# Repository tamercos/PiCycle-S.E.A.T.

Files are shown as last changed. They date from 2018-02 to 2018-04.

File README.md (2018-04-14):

# PiCycle S.E.A.T.
The PiCycle S.E.A.T. (Situational and Environmental Awareness Technology) aims to combine ultrasonic sensors with a Raspberry Pi utilising haptic feedback with the objective of increasing road safety for cyclists.

HC-SR04 ultrasonic sensors placed under the seat of the bicycle facing backwards will detect the approach of foreign objects and alert the cyclist via small vibration motors situated within the rider's helmet.



The system will increase road safety for bicycle users by allowing them to 'feel' what they cannot see behind them. Current solutions rely on wearable mirrors as wrist bands. These force cyclists to take their eyes off the road infront creating more potential dangers. The PiCycle S.E.A.T enables continuous blind spot observation without distracting the cyclist.

**A short video demonstrating the device prototype can be found here:**

https://www.youtube.com/watch?v=8pkJoHdxL40&feature=youtu.be

## Parts Used
The list below highlights some of the key hardware needed to replicate this project. Please note that circuit components can be found in the circuit schematic. A full list of this hardware with cost at time of completion is also given in "Project Components and Expenditure.xlsx"

- 3x HC-SR04 ultrasonic sensors
- 3x Seed mini vibration motor 3V 2.0mm circular
- 3D printed parts found under the "PiCycleSEAT 3D Print" folder
- 5x M2.5 x 8mm screws for the housing lid
- 4x M2.5 x 6mm screws for Raspberry Pi
- 1x Makibes Touch Screen 3.5" Resistive LCD
- 1x Long pin stack header
- 1x Perma-proto hat for Raspberry Pi Adafruit Perma-Proto Pi HAT!
- 1x 26 connection ribbon cable
- 5x 6 Way Straight Pin Header
- 1x Cable Mount IDC Connector

## Circuitry Used
The system is fully powered from the Raspberry Pi.

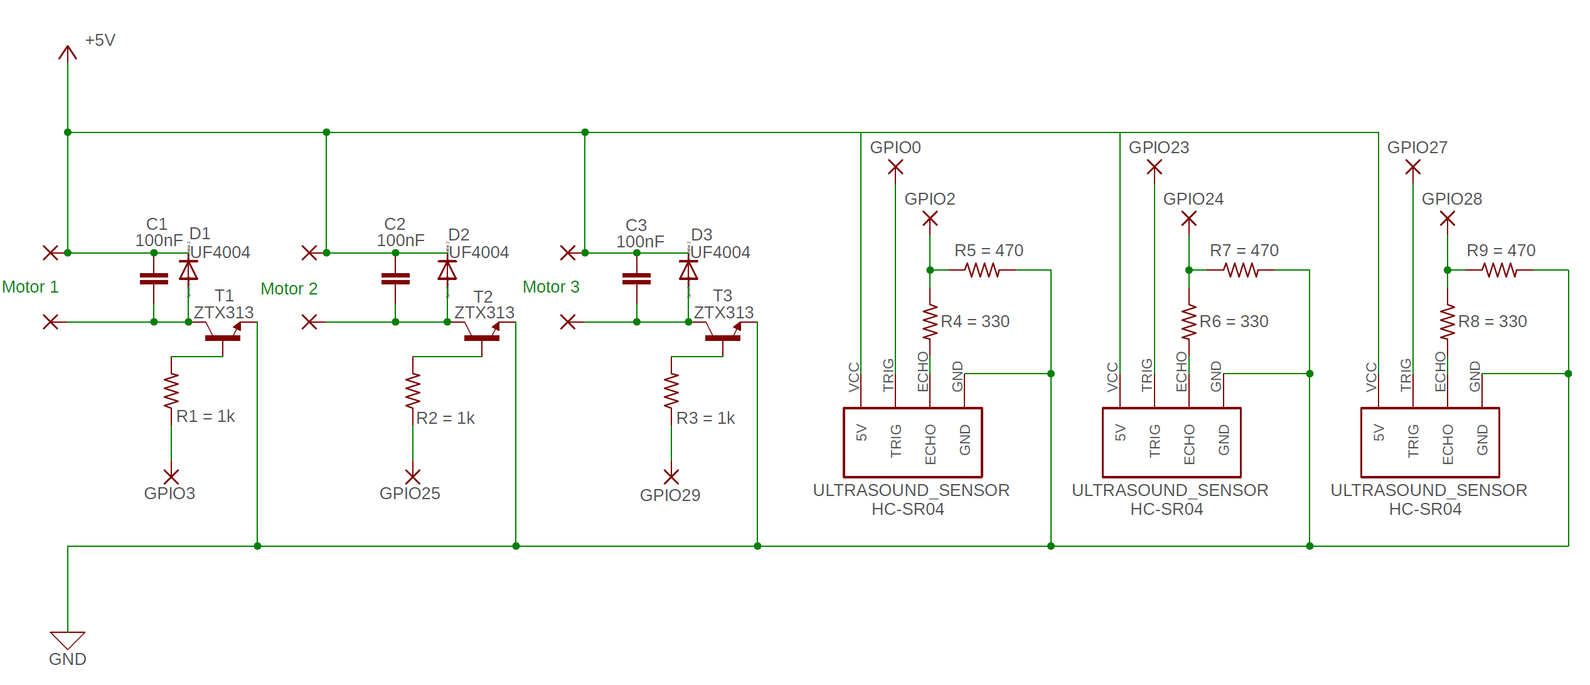
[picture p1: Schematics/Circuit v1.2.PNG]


## System Diagram
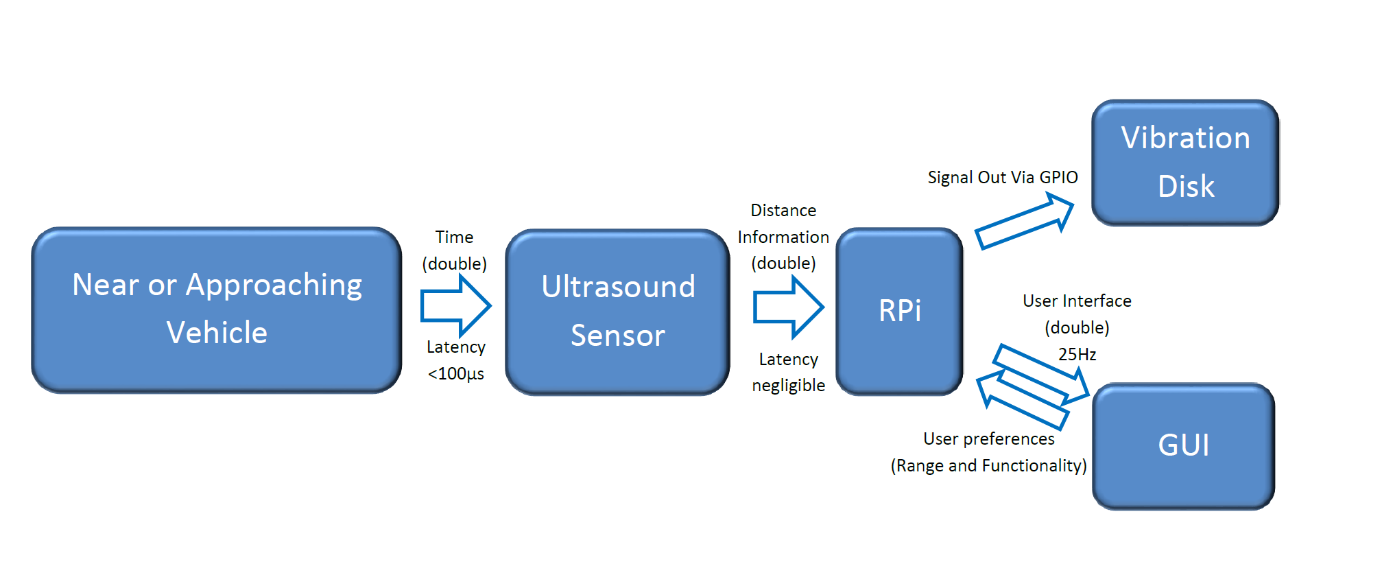
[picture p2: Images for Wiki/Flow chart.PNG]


## Social Media
We are delighted to share with you our Twitter page. You can follow all of our up to date news on the project there:

https://twitter.com/The_PiCycle

Check out our page and follow us :) 

Enjoy!

# ...Check out our Wiki for more project details and help...

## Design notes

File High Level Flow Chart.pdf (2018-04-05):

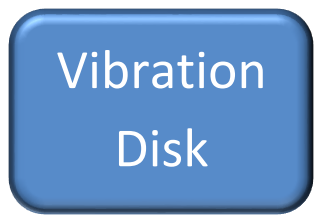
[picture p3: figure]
Vibration Disk
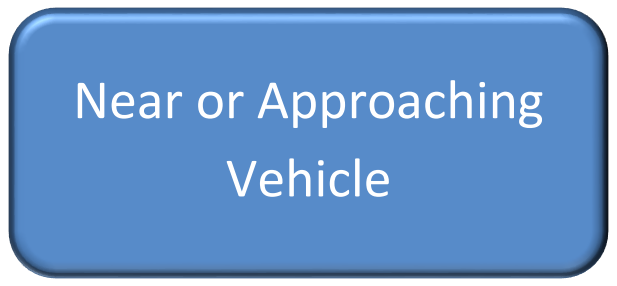
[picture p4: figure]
Near or Approaching Vehicle
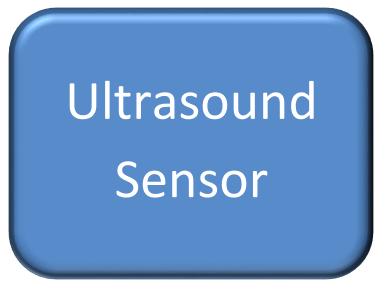
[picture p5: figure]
Ultrasound Sensor

Time
(double)

Distance
Information
(double)

Signal Out Via GPIO

User Interface
(double)
25Hz

User preferences

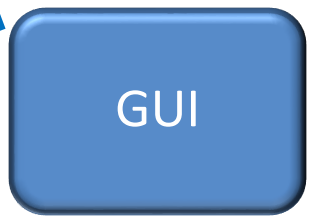
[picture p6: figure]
GUI

(Range and Functionality)

Latency
<100μs

Latency
negligible

# RPi

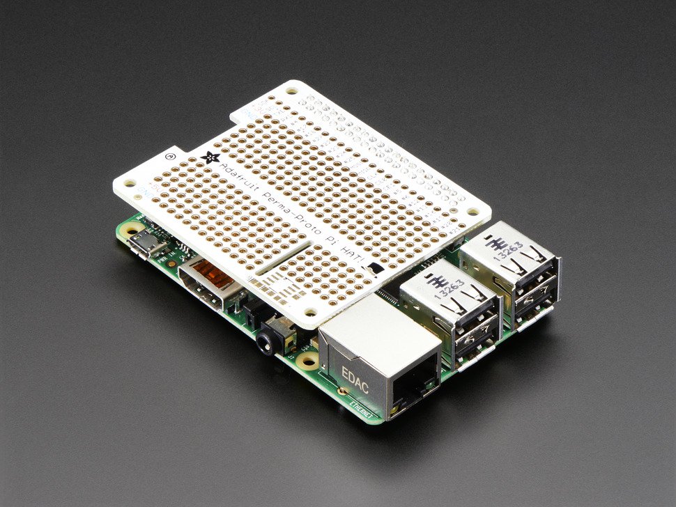
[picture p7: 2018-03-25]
Images for Wiki/Proto hat.jpg

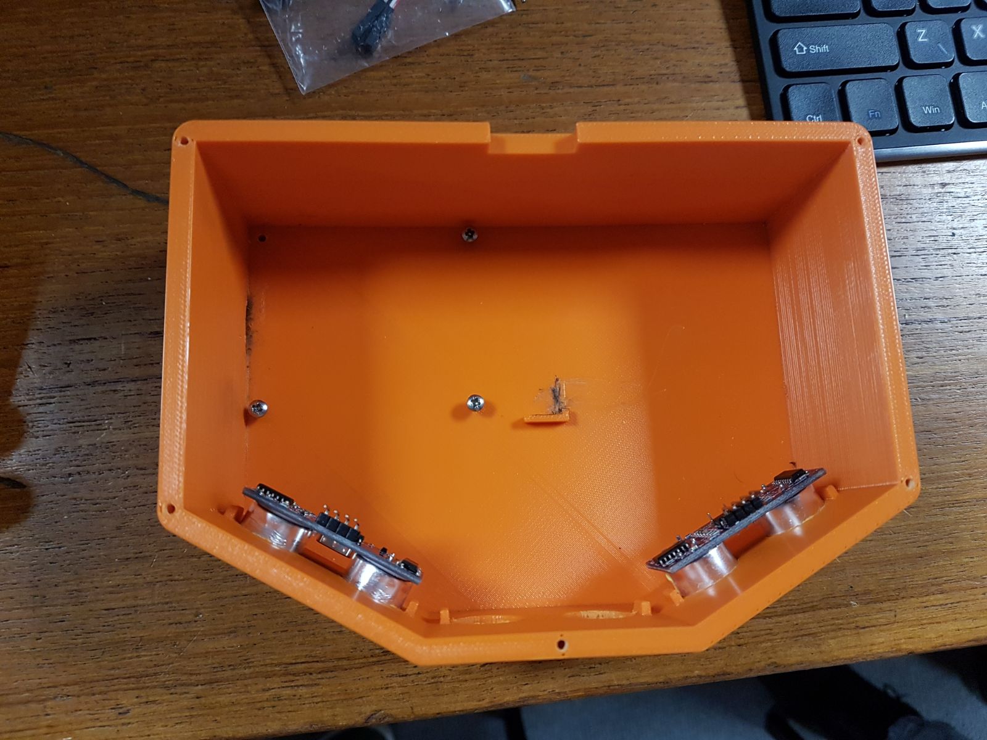
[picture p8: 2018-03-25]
Prototyping and Progress Images/Housing for sensors, RPi and PCB.jpeg

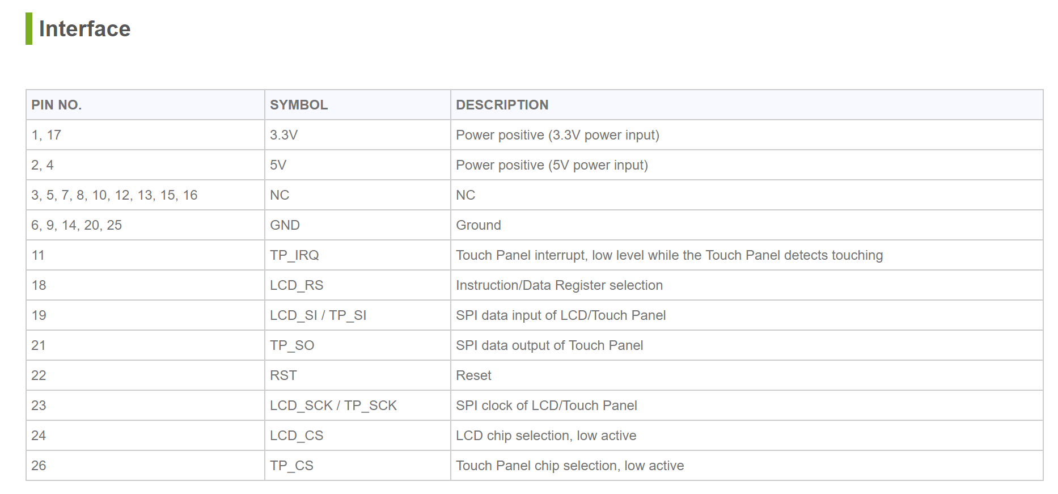
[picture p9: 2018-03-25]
Images for Wiki/Screen Connections.PNG

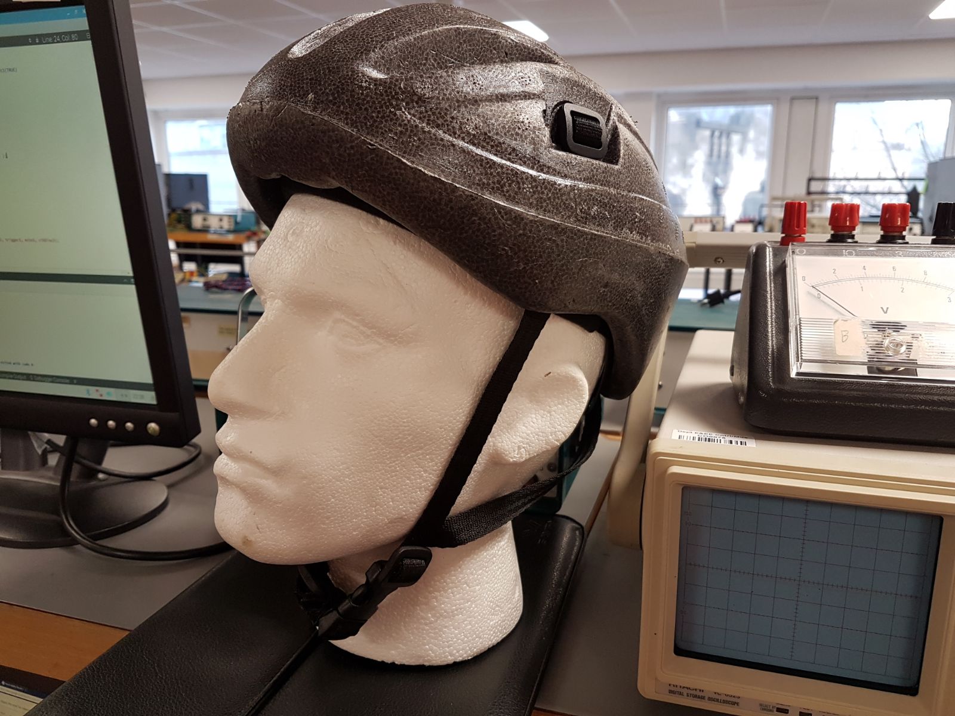
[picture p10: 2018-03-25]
Prototyping and Progress Images/George and His Helmet #feeling safer already.jpeg

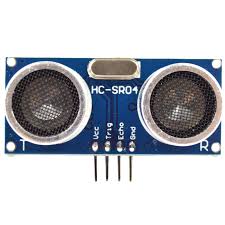
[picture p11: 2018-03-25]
Images for Wiki/HC-SR04.jpg

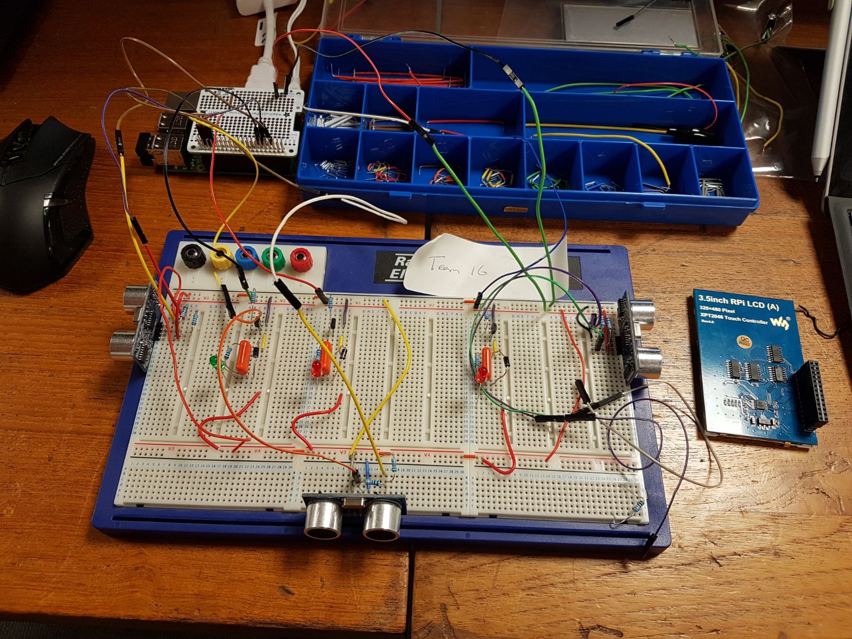
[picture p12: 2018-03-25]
Prototyping and Progress Images/Boring One.jpeg

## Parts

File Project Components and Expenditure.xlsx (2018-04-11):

PiCycle SEAT Expenditure Sheet
This excel spreadsheet shows all the major items that were purchased for the Project.
Please note that this includes buying a Raspberry Pi. This was purchased as the 1st generation of the Rpi supplied for the project was not adequate.
Links have been provided where we purchased these items. No guarantee that the prices will be the same after the date of completion for this project.
We cannot take any responsibilty for purchases that you make from these URLs provided
Item | Description | Quantity | Total Cost (GBP) | URL
HC-SR04 ultrasonic sensor | Ultrasonic sensor, Sensor angle 15 degrees, Detection distance 2cm-500cm | 3 | 6.96 | http://onecall.farnell.com/multicomp/hc-sr04/ultrasonic-distance-sensor/dp/SN36696?st=HC-SR04
Makibes Touch Screen | 3.5" Resistive LCD. 4th revision of the 3.5inch RPi LCD driven by the XPT2046 touch controller | 1 | 16.99 | https://www.amazon.co.uk/Makibes-Resolution-Display-Interface-Raspberry-pi/dp/B00UV78E9Q?s=computers
Disc Vibration Motor | Seed mini vibration motor 3V 2.0mm circular | 3 | 3.27 | https://www.rapidonline.com/seeed-316040001-mini-vibration-motor-3v-2-0mm-circular-75-0416
Jumper Wire | F-M, 40 way, 200mm | 1 | 4.86 | https://www.rapidonline.com/rapid-rw-d40-mf-jumper-wire-ribbon-dupont-cable-m-f-40-way-ribbon-200mm-34-0686
Raspberry Pi 3 | Model B | 1 | 31.28 | https://www.amazon.co.uk/Raspberry-Pi-Model-Quad-Motherboard/dp/B01CD5VC92?s=computers
Perma-Proto board | Adafruit Perma-Proto Pi HAT! | 1 | 4.65 | https://www.amazon.co.uk/Adafruit-Perma-Proto-HAT-Mini-Kit/dp/B01G3R7ONY
Stack Header | 40 Long pin stack header | 1 | 2.99 | https://www.amazon.co.uk/GPIO-Stacking-Header-Pi-Extra-long/dp/B017MSOUM6
Ribbon Cable | 3 Metre length 30 way | 1 | 6.49 | https://www.amazon.co.uk/gp/product/B077XF5LXH/ref=ox_sc_act_title_1?smid=A22LWTFCI1JO3Y&th=1
Pin Header | 6 Way Straight Pin Header | 6 | 1.20 | https://uk.rs-online.com/web/p/pcb-headers/7457046/
IDC connector | 26 way 2 row TE Connectivity AMP-LATCH Novo Series | 1 | 2.00 | https://uk.rs-online.com/web/p/products/4542384/?grossPrice=Y&matchtype=&gclsrc=aw.ds
 |  |  | Total (GBP)
 |  |  | 80.69

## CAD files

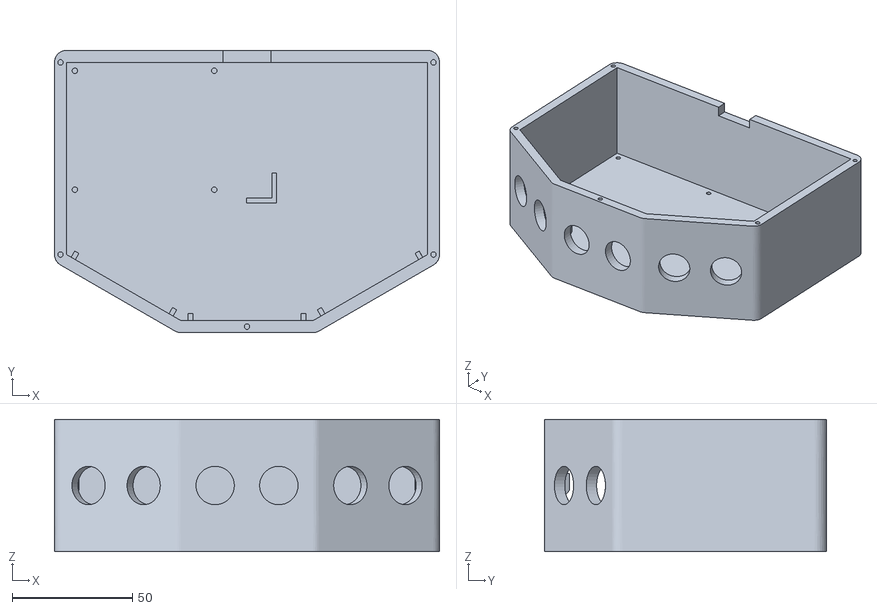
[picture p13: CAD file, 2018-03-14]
PiCycleSEAT 3D Print/HousingBase.stl
160.3 x 117.5 x 55.0

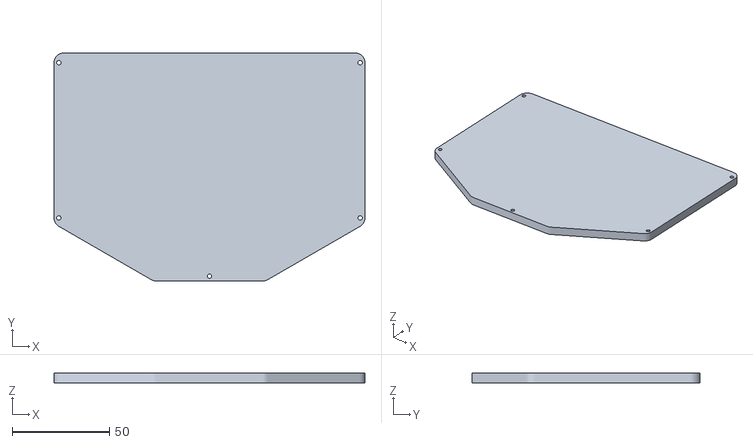
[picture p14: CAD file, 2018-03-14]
PiCycleSEAT 3D Print/HousingLid.stl
160.3 x 117.5 x 5.00

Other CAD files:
PiCycleSEAT 3D Print/HousingBase.ipt
PiCycleSEAT 3D Print/HousingLid.ipt

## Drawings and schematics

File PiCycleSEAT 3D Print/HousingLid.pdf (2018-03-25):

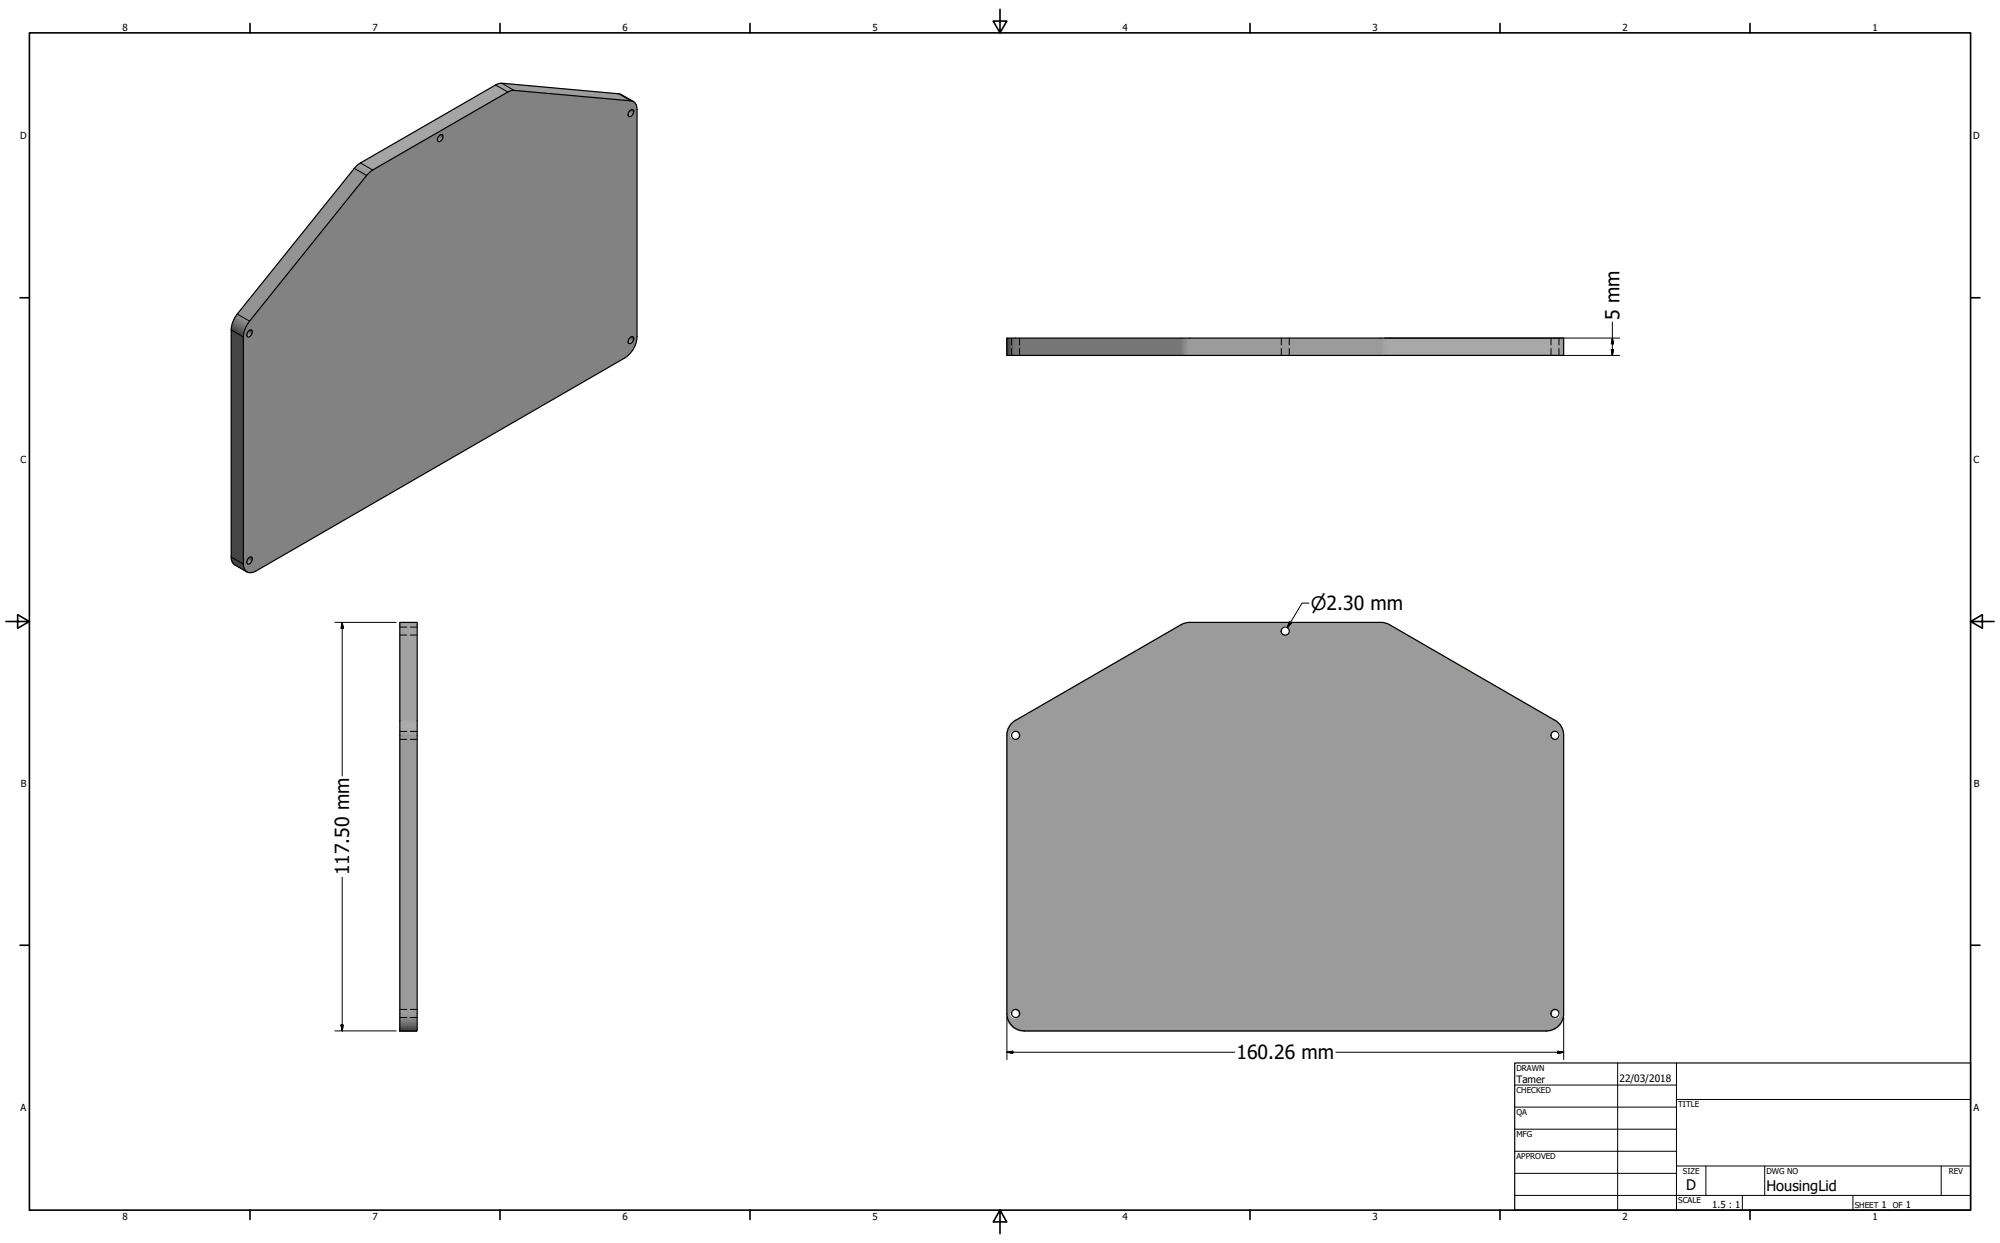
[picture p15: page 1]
SHEET 1 OF 1; DRAWN; CHECKED; MFG; APPROVED; Tamer; DWG NO HousingLid; TITLE; SIZE D; SCALE; REV

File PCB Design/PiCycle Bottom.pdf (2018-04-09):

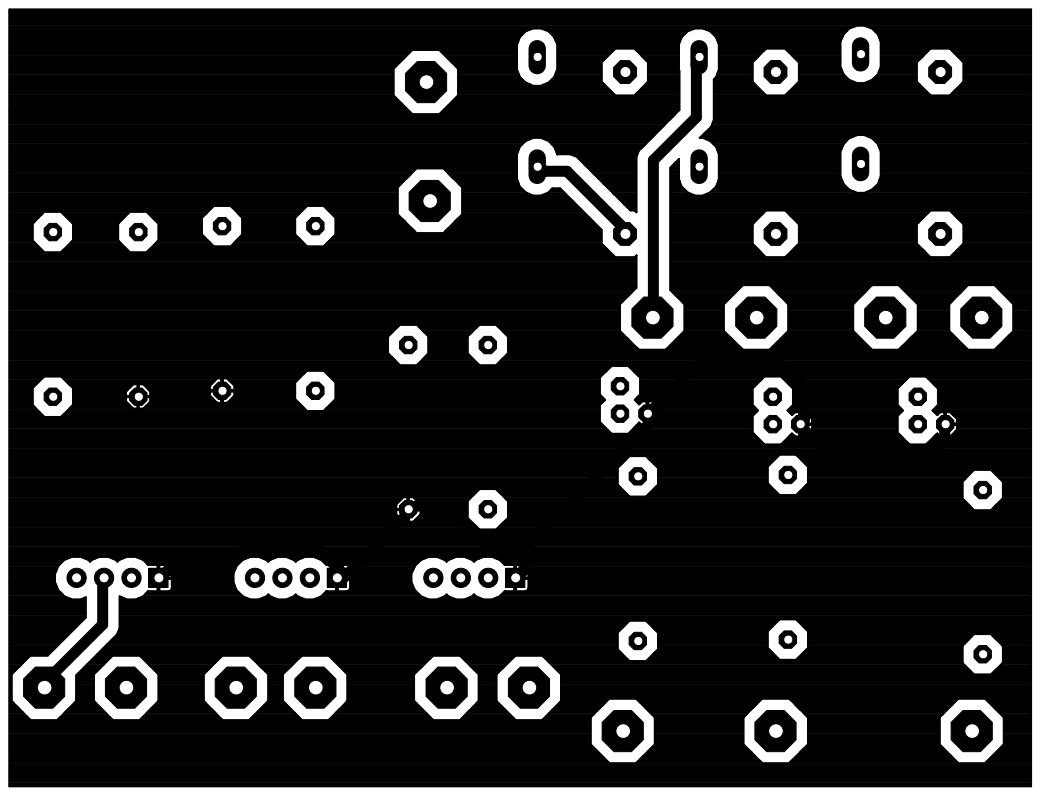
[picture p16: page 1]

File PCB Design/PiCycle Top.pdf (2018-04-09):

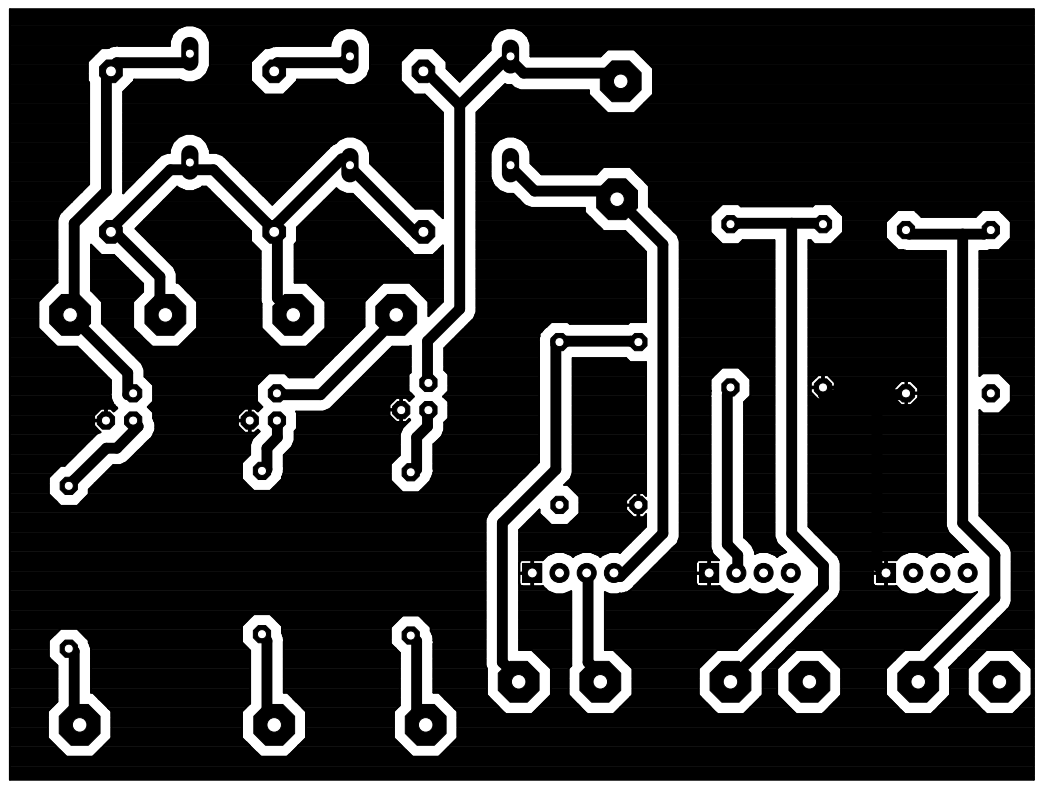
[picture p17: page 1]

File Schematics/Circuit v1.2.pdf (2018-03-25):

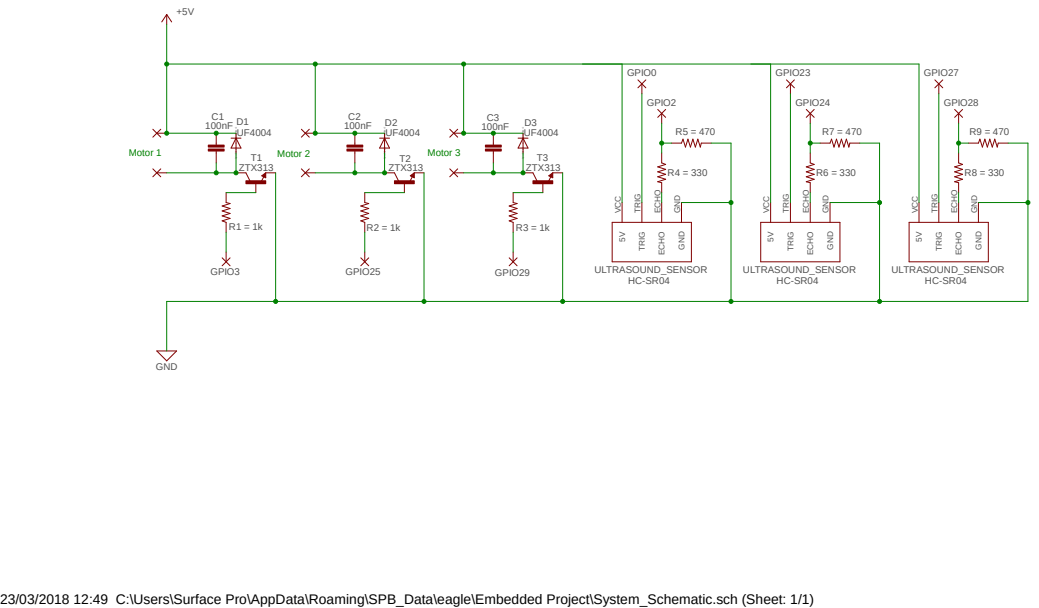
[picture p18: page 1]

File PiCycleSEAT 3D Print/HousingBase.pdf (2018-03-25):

P

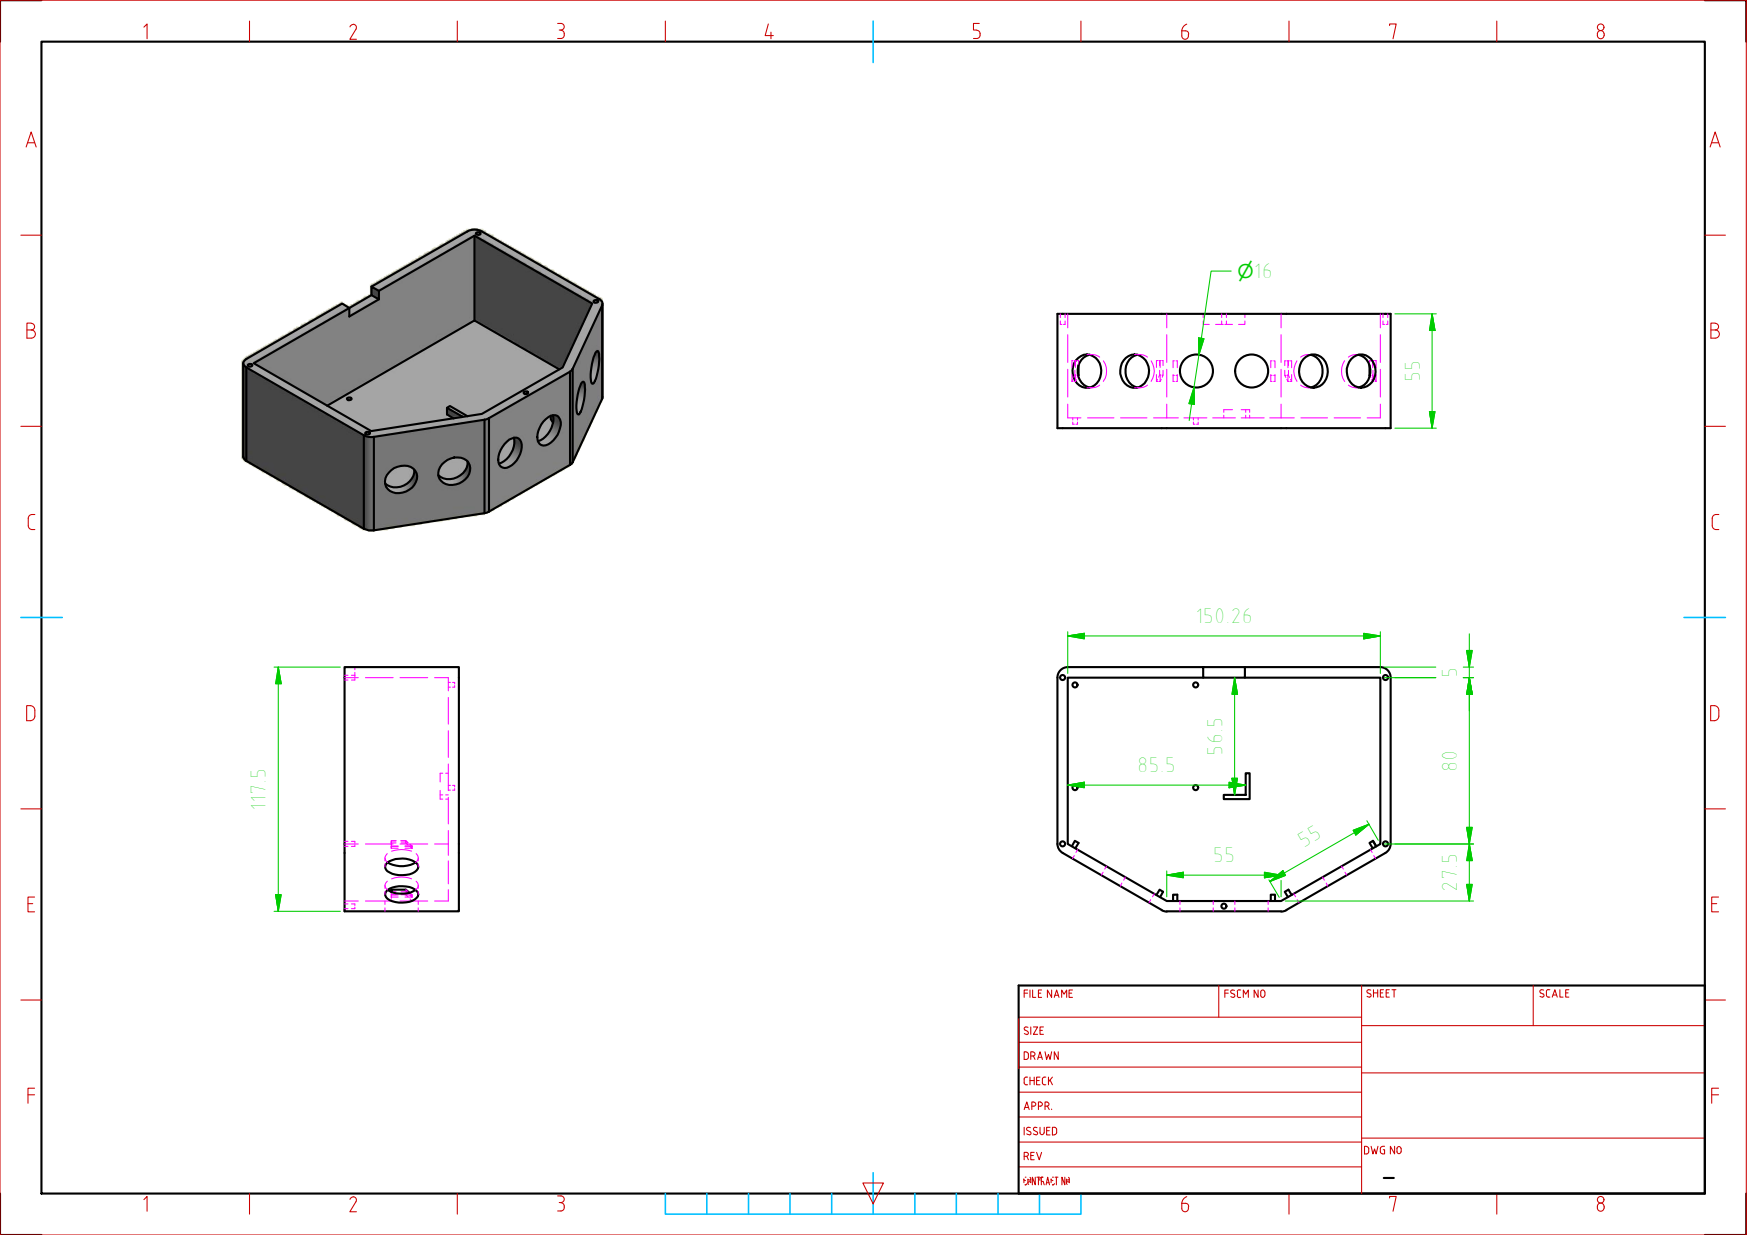
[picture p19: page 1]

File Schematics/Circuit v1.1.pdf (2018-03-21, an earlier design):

GPIO | GPIO | GPIO ²N⁷⁰⁶ | 2N⁷⁰⁶ | 2N⁷⁰⁶ BA²⁴³A | BA²⁴³A | BA²⁴³A ⁺⁵V | HC⁻SR⁰⁴
PAD9 | GND GND | ECHO ECHO | TRIG TRIG | 5V VCC J_ULTRASONIC_1

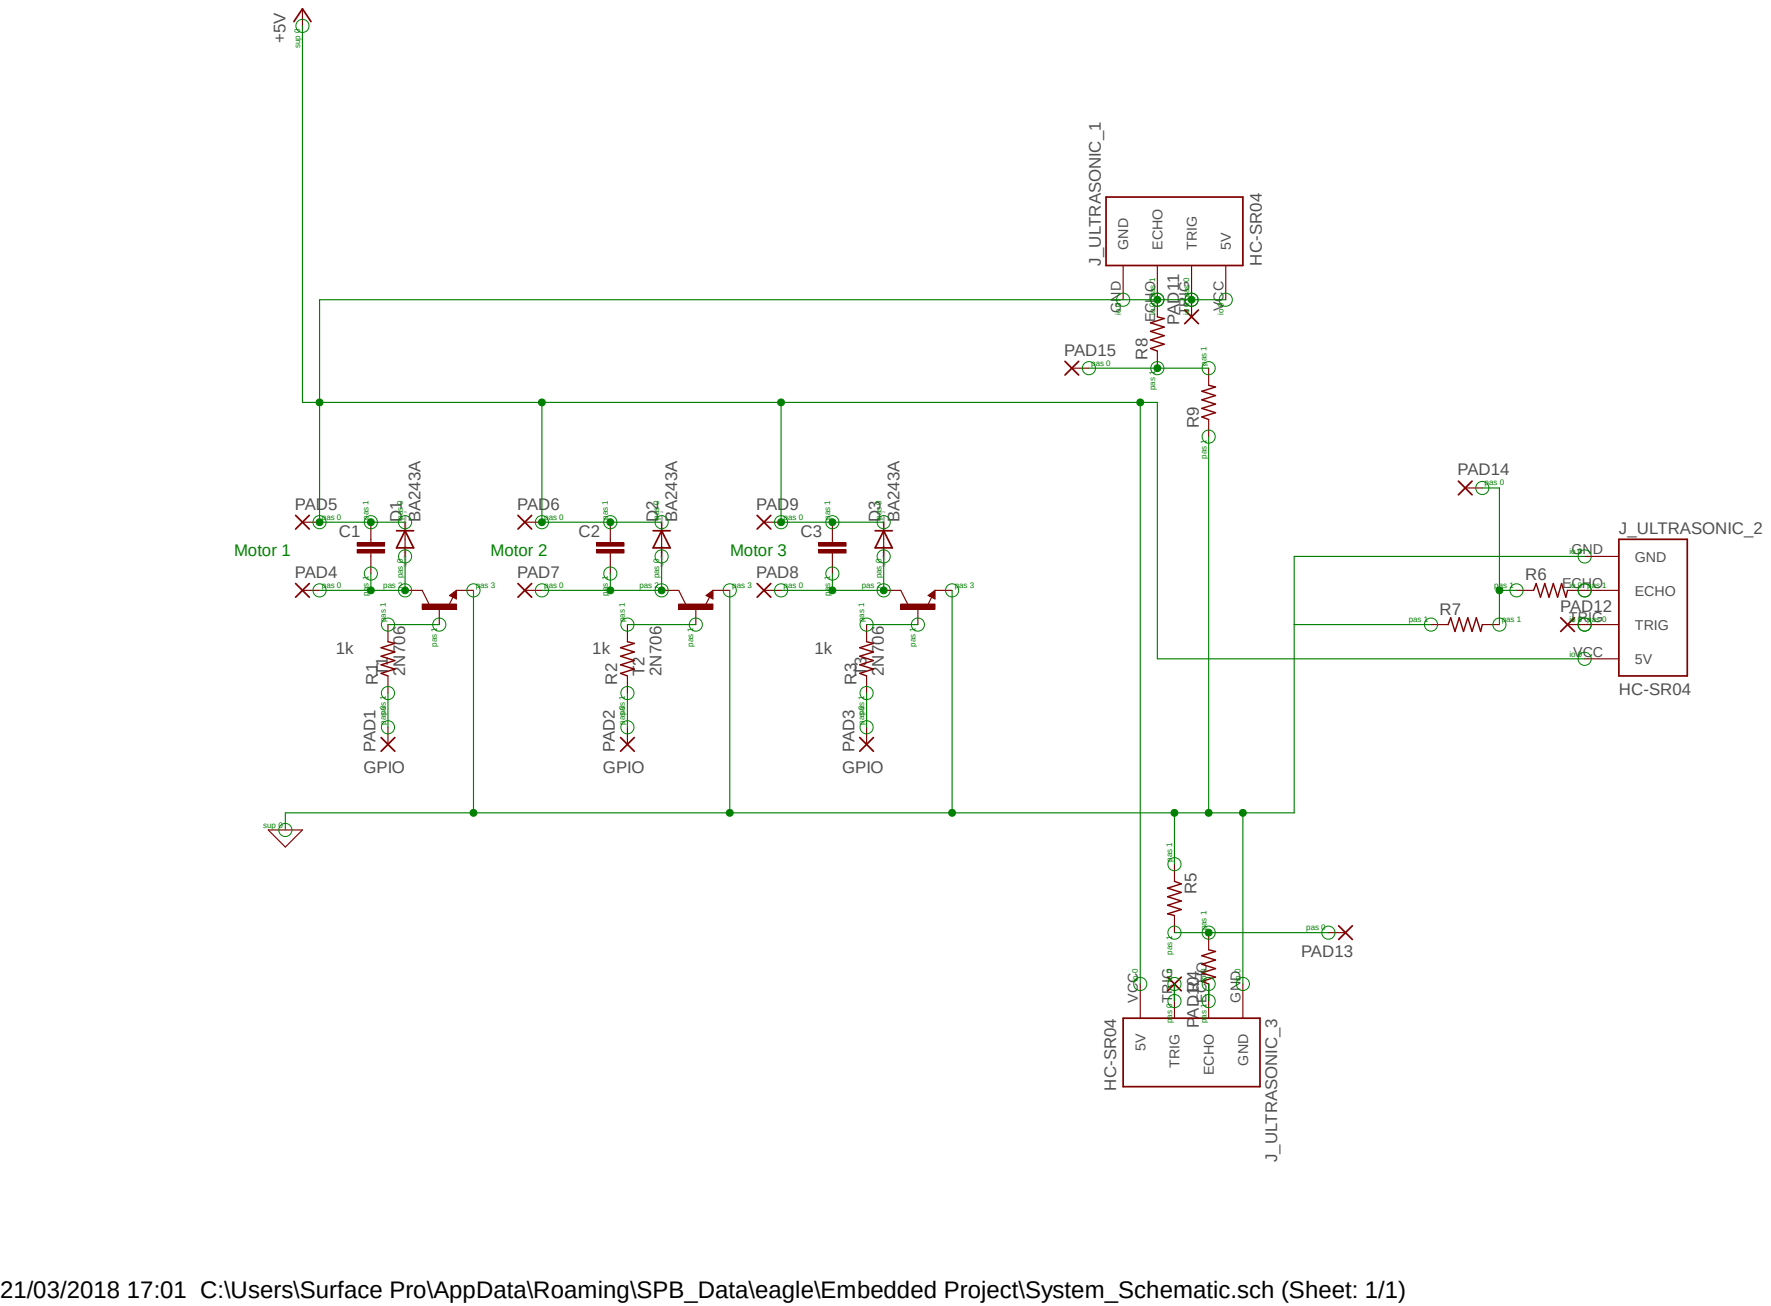
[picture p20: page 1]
21/03/2018 17:01 C:\Users\Surface Pro\AppData\Roaming\SPB_Data\eagle\Embedded Project\System_Schematic.sch (Sheet: 1/1) SpiceOrder 1 SpiceOrder 2; SpiceOrder 1 SpiceOrder 2; HC-SR04 HC⁻SR⁰⁴ R¹; R³ PAD¹; PAD²; PAD³ T1; PAD4; PAD5; PAD6; PAD7; PAD8; GND GND; ECHO ECHO; TRIG TRIG; 5V VCC J_ULTRASONIC_2 GND GND ECHO ECHO TRIG TRIG 5V VCC; J_ULTRASONIC_3PAD¹⁰ PAD¹¹; PAD12 R⁴ R⁵; PAD13; PAD14; PAD15; sup 0; pas 1 pas 1; pas 1 pas 1 pas 0; pas 0; pas 0 pas 1; pas 2; pas 3; pas 1; pas 3 pas 0 pas 0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

pas 0 pas 1 pas 1 pas 1 pas 1

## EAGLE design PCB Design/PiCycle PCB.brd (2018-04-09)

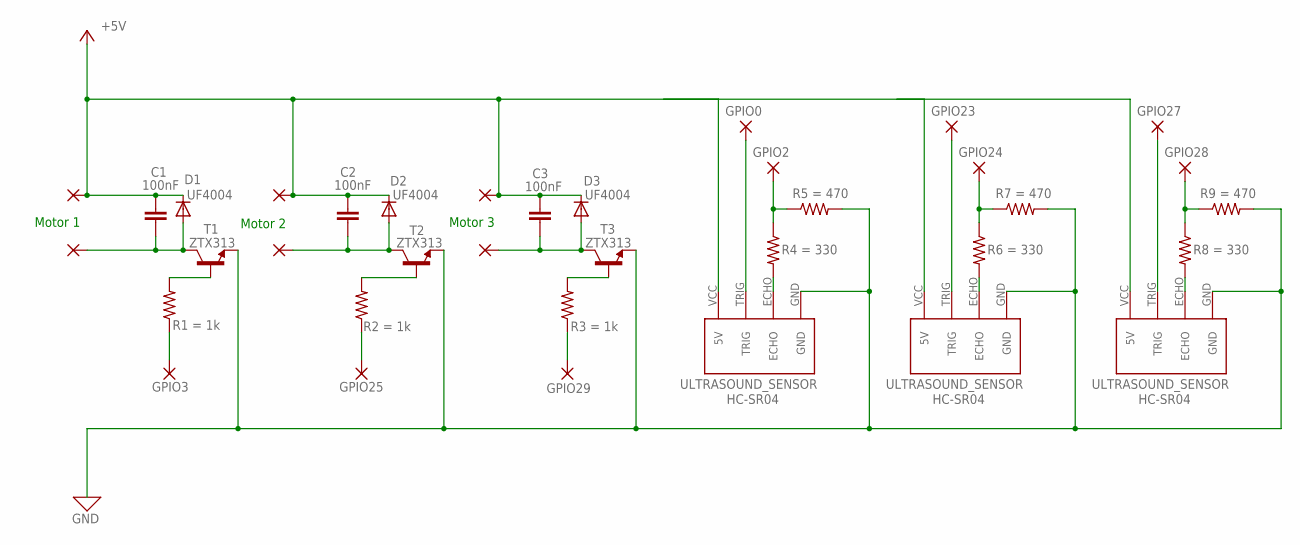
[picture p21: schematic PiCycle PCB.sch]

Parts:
C1, C2, C3: C15/6; C15B6
D1, D2, D3: BA243A; DO35-10
J_ULTRASONIC_1, J_ULTRASONIC_2, J_ULTRASONIC_3: HC-SR04; HC-SR04_FOOTPRINT
PAD1, PAD2, PAD3, PAD4, PAD5, PAD6, PAD7, PAD8, PAD9, PAD10, PAD11, PAD12, PAD13, PAD14, PAD15: 3,81/1,4
R1, R2, R3, R4, R5, R6, R7, R8, R9: R-US_0207/15; 0207/15
T1, T2, T3: 2N706; TO18

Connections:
0: J_ULTRASONIC_1.GND, J_ULTRASONIC_2.GND, J_ULTRASONIC_3.GND, R5.2, R7.2, R9.2, T1.1 (E), T2.1 (E), T3.1 (E)
+5V: C1.1, C2.1, C3.1, D1.C, D2.C, D3.C, J_ULTRASONIC_1.VCC (5V), PAD5.1, PAD6.1, PAD9.1
+5V1: J_ULTRASONIC_2.VCC (5V)
+5V2: J_ULTRASONIC_3.VCC (5V)
unnamed: PAD1.1, R1.1
unnamed: PAD2.1, R2.1
unnamed: PAD3.1, R3.1
unnamed: R1.2, T1.2 (B)
unnamed: R2.2, T2.2 (B)
unnamed: R3.2, T3.2 (B)
unnamed: C1.2, D1.A, PAD4.1, T1.3 (C)
unnamed: C2.2, D2.A, PAD7.1, T2.3 (C)
unnamed: C3.2, D3.A, PAD8.1, T3.3 (C)
unnamed: J_ULTRASONIC_2.TRIG, PAD10.1
unnamed: J_ULTRASONIC_1.TRIG, PAD11.1
unnamed: J_ULTRASONIC_2.ECHO, R4.2
unnamed: J_ULTRASONIC_1.ECHO, R8.2
unnamed: PAD15.1, R8.1, R9.1
unnamed: PAD12.1, R4.1, R5.1
unnamed: J_ULTRASONIC_3.TRIG, PAD13.1
unnamed: J_ULTRASONIC_3.ECHO, R6.2
unnamed: PAD14.1, R6.1, R7.1

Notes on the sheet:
Motor 1
Motor 2
Motor 3

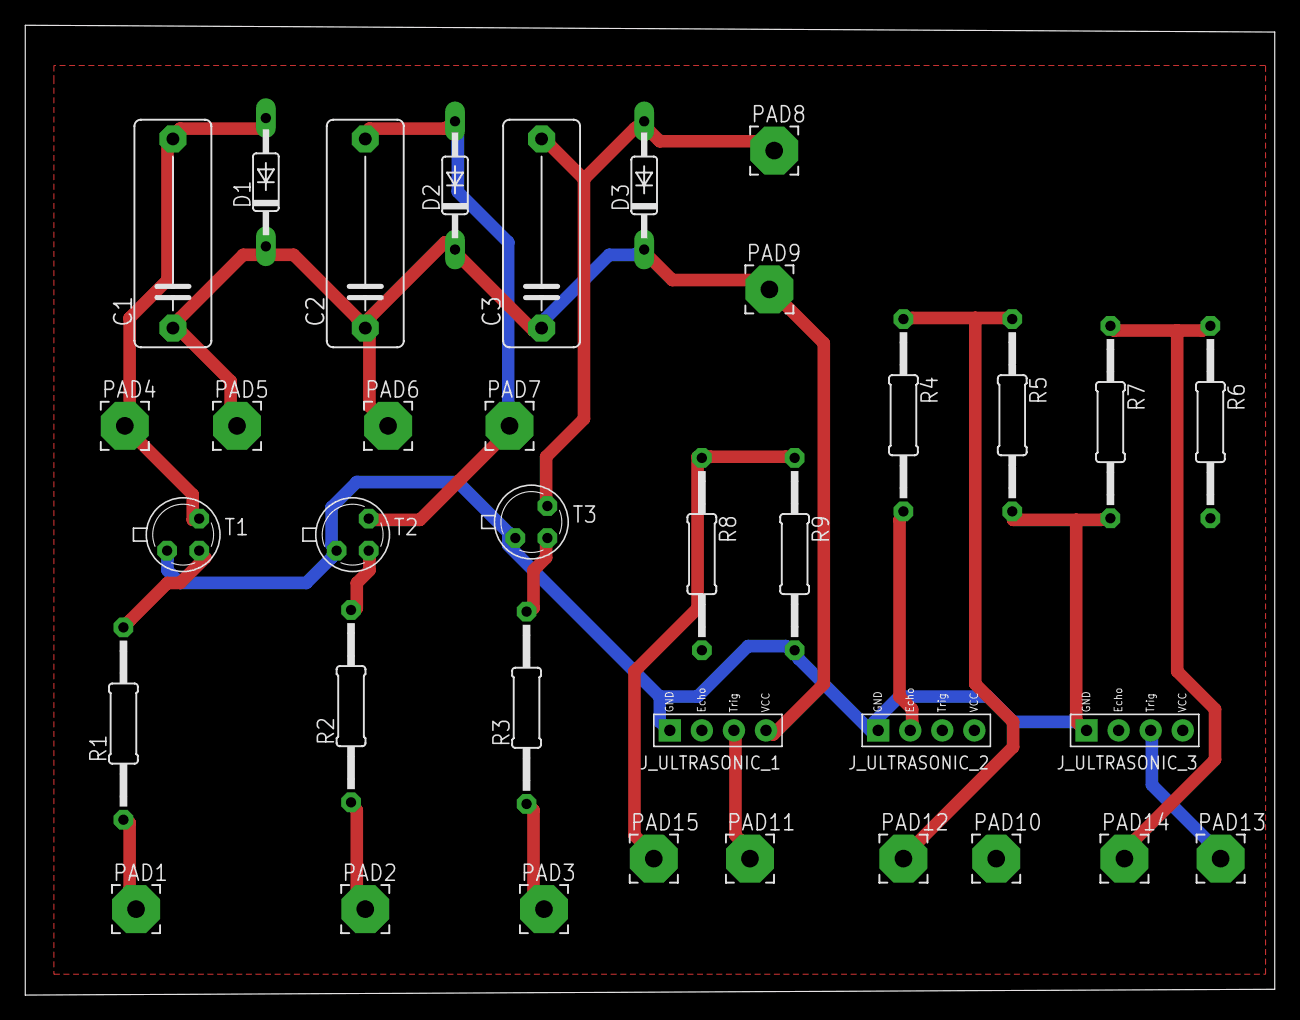
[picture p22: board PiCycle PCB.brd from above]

Board: 2 copper layers, 99.0 x 76.8 mm, 36 parts (0 on the bottom side), 20 nets.

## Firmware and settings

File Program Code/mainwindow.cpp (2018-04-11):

#include "mainwindow.h"
#include "libSonar.h"
#include <wiringPi.h>
#include "ui_mainwindow.h"
#include <QCheckBox>
#include <QScrollBar>
#include <iostream>
#include <iomanip>

MainWindow::MainWindow() : detectRange(10), vibInput1(TRUE), vibInput2(TRUE), vibInput3(TRUE)
{
   Sonar sonar;

 /**********************************
  * Assigning widget functionality *
  **********************************/
    checkBox1 = new QCheckBox("Disable left");
    connect( checkBox1, SIGNAL(clicked(bool)), SLOT(setVibInput1(bool)) );

    checkBox2 = new QCheckBox("Disable back");
    connect( checkBox2, SIGNAL(clicked(bool)), SLOT(setVibInput2(bool)) );

    checkBox3 = new QCheckBox("Disable right");
    connect( checkBox3, SIGNAL(clicked(bool)), SLOT(setVibInput3(bool)) );

    scrollbar = new QScrollBar(Qt::Horizontal);
    scrollbar->setValue(detectRange);
    scrollbar->setRange(0, 300);                 //setting the scrollbar range between 0 to 3 meters
    connect( scrollbar, SIGNAL(valueChanged(int)), SLOT(setDetectRange(int)) );

    sblabel = new QLabel;
    sblabel->setText("Set detection range (0m-3m)");

 /********************
  * set up UI layout *
  ********************/
    vLayout = new QVBoxLayout;
    vLayout->setContentsMargins(30,60,30,80);
    vLayout->addWidget(sblabel);
    sblabel->setAlignment(Qt::AlignCenter);
    vLayout->addWidget(scrollbar);

    hLayout = new QHBoxLayout;
    hLayout->setContentsMargins(10,50,0,0);
    hLayout->addWidget(checkBox1);
    hLayout->addWidget(checkBox2);
    hLayout->addWidget(checkBox3);
    vLayout->addLayout(hLayout);

    setLayout(vLayout);

}

void MainWindow::setVibInput1(bool vibInput1)           //Varies value between TRUE and FALSE upon each click of the checkbox
{
    this->vibInput1 = !vibInput1;
}

void MainWindow::setVibInput2(bool vibInput2)
{
    this->vibInput2 = !vibInput2;
}

void MainWindow::setVibInput3(bool vibInput3)
{
    this->vibInput3 = !vibInput3;
}

void MainWindow::setDetectRange(int detectRange)
{
    this->detectRange = detectRange;
}


/******************************************
 * Timer event that will run continuously *
 ******************************************/
void MainWindow::timerEvent( QTimerEvent * )
{

     if (vibInput1 == TRUE){                                    //vibInput is tied to the checkbox. If checkbox value is TRUE, then run the following IF loop. Otherwise, default to deactive

            if (sonar.distance1(3333) < detectRange){           //vibration disc1 condition for activation. If distance is less than the detection range, vibration disc is activated
                digitalWrite (sonar.getVibDisc1(), HIGH);
                }
                else{                                           //otherwise, the vibration disc is deactivated
                       digitalWrite (sonar.getVibDisc1(), LOW);
                    }
            }

        else{
               digitalWrite (sonar.getVibDisc1(), LOW);
            }

     if (vibInput2 == TRUE){

            if (sonar.distance2(3333) < detectRange){			//vibration disc2 condition for activation
                digitalWrite (sonar.getVibDisc2(), HIGH);
                }
                else{
                       digitalWrite (sonar.getVibDisc2(), LOW);
                    }
        }
        else{
               digitalWrite (sonar.getVibDisc2(), LOW);
            }


     if (vibInput3 == TRUE){
            if (sonar.distance3(3333)  < detectRange){			//vibration disc3 condition for activation
                digitalWrite (sonar.getVibDisc3(), HIGH);
            }
                else{
                       digitalWrite (sonar.getVibDisc3(), LOW);
                    }
        }
        else{
               digitalWrite (sonar.getVibDisc3(), LOW);
            }

        std::cout << "Left: " << std::setprecision(3) << sonar.distance1(3333) << " cm // " << "Back: " << std::setprecision(3)
        << sonar.distance2(3333) << " cm // " << "Right: " << std::setprecision(3) << sonar.distance3(3333) << "cm" << std::endl;

}

MainWindow::~MainWindow()
{

}

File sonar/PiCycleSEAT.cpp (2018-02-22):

#include <iostream>
#include <wiringPi.h>
#include "libSonar.h"

using namespace std;

//***Decleration of wpi pin connections***
int trigger1 = 7;
int echo1 = 0;
int motor1 = 1;

int trigger2 = 4;
int echo2 = 5;
int motor2 = 3;

int trigger3 = 4;	//These pins are to change upon arrival of RPi 3!!!
int echo3 = 2;
int motor3 = 6;


int main()
{
    if (wiringPiSetup() == -1)
        return -1;

    Sonar sonar;
    sonar.init(trigger1, echo1, motor1, trigger2, echo2, motor2, trigger3, echo3, motor3);

    while(1)
    {
        
        if (sonar.distance1(30000) < 10.0){				//motor1 condition for activation
			digitalWrite (motor1, HIGH);
		}
			else{
					digitalWrite (motor1, LOW);
				}
        
        
        if (sonar.distance2(30000) < 10.0){				//motor2 condition for activation
			digitalWrite (motor2, HIGH);
		}
			else{
					digitalWrite (motor2, LOW);
				}
				
				
		if (sonar.distance3(30000) < 10.0){				//motor3 condition for activation
			digitalWrite (motor3, HIGH);
		}
			else{
					digitalWrite (motor3, LOW);
				}
			
			
		cout << "1st distance is " << sonar.distance1(30000) << " cm : " << "2nd distance is " << sonar.distance2(30000) << " cm : " << "3rd distance is " << sonar.distance3(30000) << "cm" << endl;
	}    

}

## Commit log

2018-01-18 Sample code
    Made a quick "hello world" varient to test out github
2018-01-24 led blinker added
2018-01-31 Motor stuff
2018-02-06 Motor code update
    Using wiringPi library to address gpio. This fixes bug where the programme requires to be interupted for subsequent runs to be succesful.
2018-02-07 Add files via upload
    code for ultrasonic sensor
2018-02-07 Add files via upload
    on website
    https://ninedof.wordpress.com/2013/07/16/rpi-hc-sr04-ultrasonic-sensor-mini-project/
2018-02-15 Early Code for Ultrasound working with motors
    We reached reading data from 2 ultrasound sensors simultaneously but could not trigger the motors independantly yet.
    May be issue with the physical circuitry or a small bug in the software.
    [libSonar.cpp, libSonar.h]
2018-02-15 Updated code. Motors run Independantly with third motor activating when motors 1 and 2 are on
    The previous version of the code was fine but we had a fault with the circuitry that was causing the vibrating motors to all drive at the same time. This problem has been resolved. The new code is a result of this error being fixed and the addition then of outputting a third motor when both motor 1 and 2 are active. This was done because the third ultrasound was faulty but while waiting for another, the GPIO pin was set to an output and is something useful at least. The motor is replaced with an LED acting as an indicator when both motors1 and 2 are active
    [libSonar.cpp, libSonar.h]
2018-02-22 PiCycle SEAT
    Added code for three sonars and motors to function independantly
2018-03-01 3D printed parts that are used in this project
    [HousingBase.ipt, HousingBase.stl, HousingLid.ipt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]
2018-03-07 Bug fix
    Fixed a bug where pinMode was not declaring INPUT/OUTPUT correctly
    [PiCycleSEAT.cpp, libSonar.cpp, libSonar.h]
2018-03-14 Updated .stl files
    There was an oversight when exporting the .stl files where the component would be 10x smaller than desired. This has now been accounted for.
    [HousingBase.dwg, HousingBase.ipt, HousingBase.stl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]
2018-03-14 Minor changes
    Added simple option to change sample rate in code as well as some other small changes
2018-03-16 W.I.P.
    Currently disfunctional
2018-03-21 v1.1 Circuitry
    Early schematic. Component names and values to be added/tidied. Connector pad labels to be added.
    .sch and .brd files will be added at a later date
2018-03-21 V2.0
    Minimum viable product of code running with GUI now functional. A spinbox to vary the detection range of the sensors has been added.
    This is the absolute bare minimum for the GUI in its current state. Implementation of further GUI elements to come.
2018-03-22 CAD model drawings available as PDFs
    [HousingBase.dwg]
2018-03-23 Removing old circuit
    Circuit with wrong component names and untidy layout
2018-03-23 Circuit diagram
    New v1.2 is an updated circuit with correct component names and values. As working prototype.
    Generally neater layout
2018-03-23 Circuit PNG
    For Readme
2018-03-23 Circuit Diagram to readme
    added general schematic to readme file
2018-03-23 EAGLE .sch file
    .sch file of circuit can be opened and edited using EAGLE
    [System_Schematic.sch]
2018-03-23 Some Images of our initial stages in prototyping
    Enjoy!
2018-03-23 System Flow Chart
    A high level diagram of the system
2018-03-23 V2.1
    - Replaced spinbox with scrollbar for setting the detection range of the senors.
    - Added checkboxes to activate/deactivate select vibration discs
    - cleanup
    [PiCycleSEAT.cpp, libSonar.cpp, libSonar.h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]
2018-03-25 V2.2
    - Additional comments added to code for clarity
    - Folder structure reorganised for clarity
    - Bug fix: disabling a vibration disc in the UI would actually just freeze its last state (i.e. if the vibration disc was ON when "disabled" then vibration would persist perpetually). This bug has now been fixed.
    [HousingBase.dwg]
2018-04-04 disappeared circuit diagram replaced in readme file
2018-04-04 Operation of the ultrasound sensor
2018-04-04 Images and videos of prototype
2018-04-04 Prototype Stages
    Before the system is wireless, we have a nice prototype of the vibration discs fixed to the inner band of a bicycle helmet
2018-04-05 A list of the components purchased and used
    Here you can find all the items needed for this project and the cost (05/04/2018)
    [Project Components and Expenditure.xlsx]
2018-04-05 FLow Chart of System
    Highlighting the processes and comms method
2018-04-05 Flow chart of system
2018-04-09 PCB Design Files
    Here we have the files to open the PCB on Eagle. If you don't have this program then feel free to just use the PDF files. The back surface of the PCB has been mirrored already and fully ready for pri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
    [PiCycle PCB.brd, PiCycle PCB.sch]
2018-04-11 List of Components for this project and cost
    update in file disclaimer
    [Project Components and Expenditure.xlsx]
2018-04-11 V2.4
    Bug fix where variables were not initialised properly
    [libSonar.cpp, libSonar.h, main.cpp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]
2018-04-14 README
    Included youtube link to prototype demonstration
